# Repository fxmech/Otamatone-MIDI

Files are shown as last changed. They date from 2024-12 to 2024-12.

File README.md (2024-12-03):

Time lapse video of the full build available on my Youtube Page @fxmech314
https://youtu.be/D1--f7NfiHk?si=KnY27Ke7BcFxFsHI

The neck slider pot is not a potentiometer, but rather a rheostat, so while my wiring solution works, the output rage is limited from the usual 1024 steps down to 500...  I will need to revisit this.

The software has 3 modes.  
1: similar to original where the neck is just a long pitch bend wheel
2: Neck is mapped into a specific Major scale
3: Neck is mapped into a specific minor scale
The mode is mapped to the original 3 position switch on the Otamatone.

The Original volume know is also used to send midi signals to control volume or anything else you choose to map it too.

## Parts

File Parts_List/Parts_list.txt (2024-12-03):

1Pc Otamatone Techno.   I would guess that this would work on any full Sized Otamatone, but I cant be sure.  I did my build based on the Techno model.

1pc Ableton Live Software or similar to generate the audio...  It can also be a midi sound device such as a keyboard or sound module that accepts midi signals.  T

2pcs Uxcell 5pcs Fader Variable Resistors Mixer 18mm Straight Slide Potentiometer B102 B1K Ohm Linear Single Potentiometers for Dimming Tuning
Amazon $9.49 for pack of 5
https://www.amazon.com/dp/B07VY7TL75?ref=ppx_yo2ov_dt_b_fed_asin_title&th=1

1pc SeeedStudio XIOA SAMD21 microcontroller  $5.40 each
Mouser.com
https://www.mouser.com/ProductDetail/Seeed-Studio/102010328?qs=GBLSl2AkirtQWO8CTzEK9g%3D%3D

Resistors:
3pcs 10K Ohm for Selection Switch
1pc 120K Ohm resistor for neck Rheostat. Can be a 100K Ohm in series with a 22k Ohm as in the wiring diagram
 
NOTE:  This value might vary depending on the consistency in the original Otamatone parts.  I suggest starting with 120K and then adjusting up and down while looking at values on the Arduino debugger.  The idea resistance is the one that gives you the largest range in values.  I was getting about 500 range.  doesn't need to start at zero... just subtract the lowers value from the highest value and that is your range...  Go for the resistor that makes that number as high as possible.  In the future I will revisit this in order to raise the range to at least the full 0-1024.

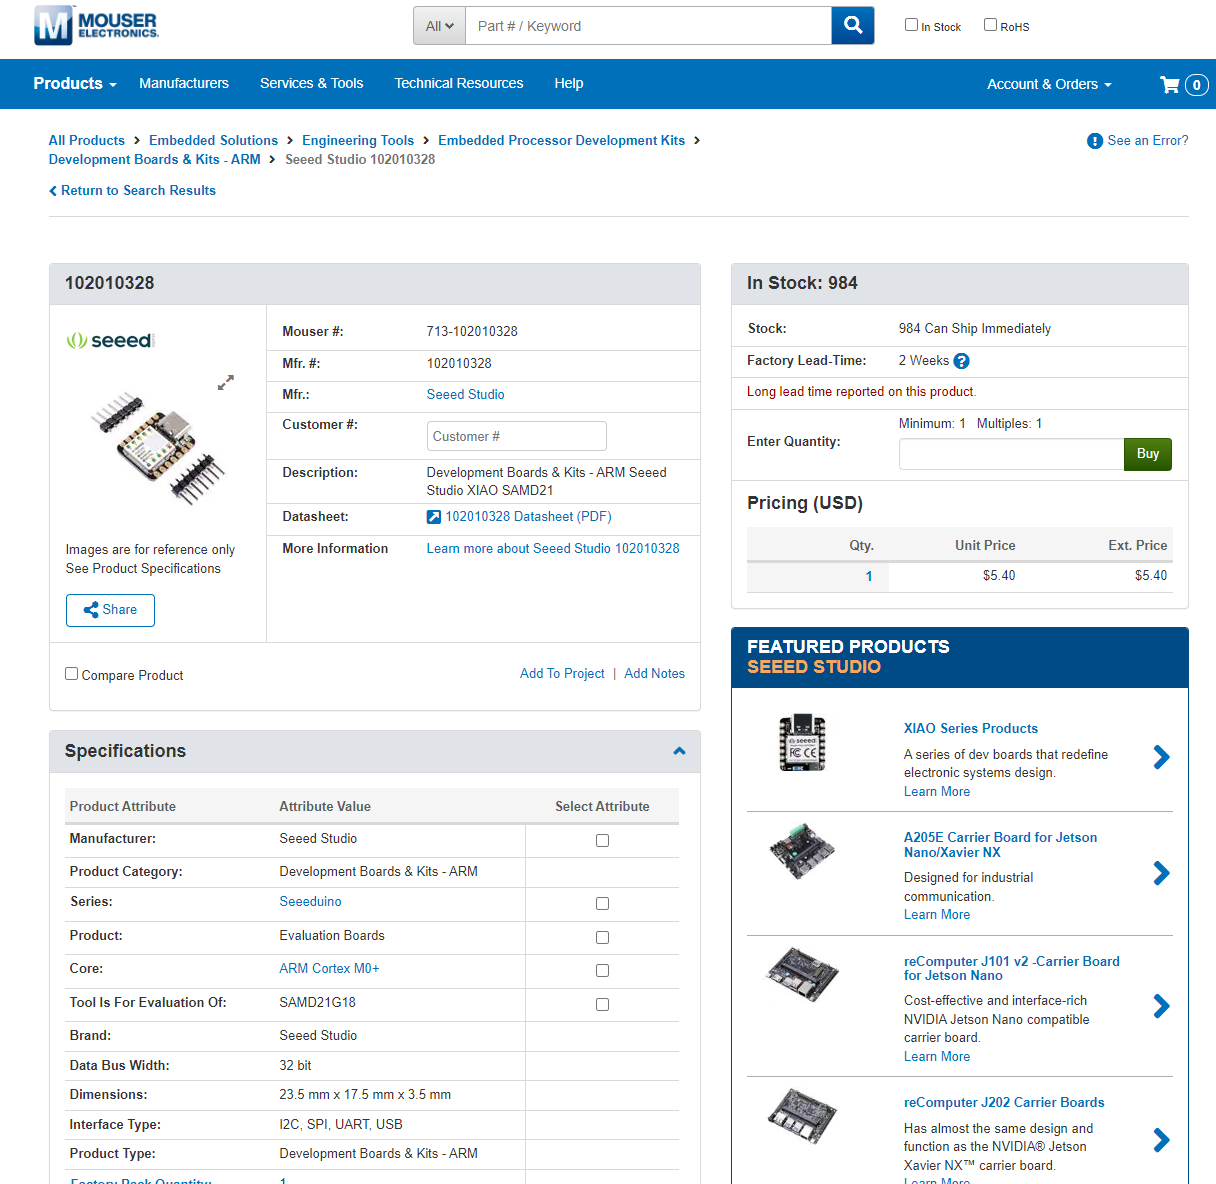
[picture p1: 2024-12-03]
Parts_List/Screenshot 2024-12-02 131504.png

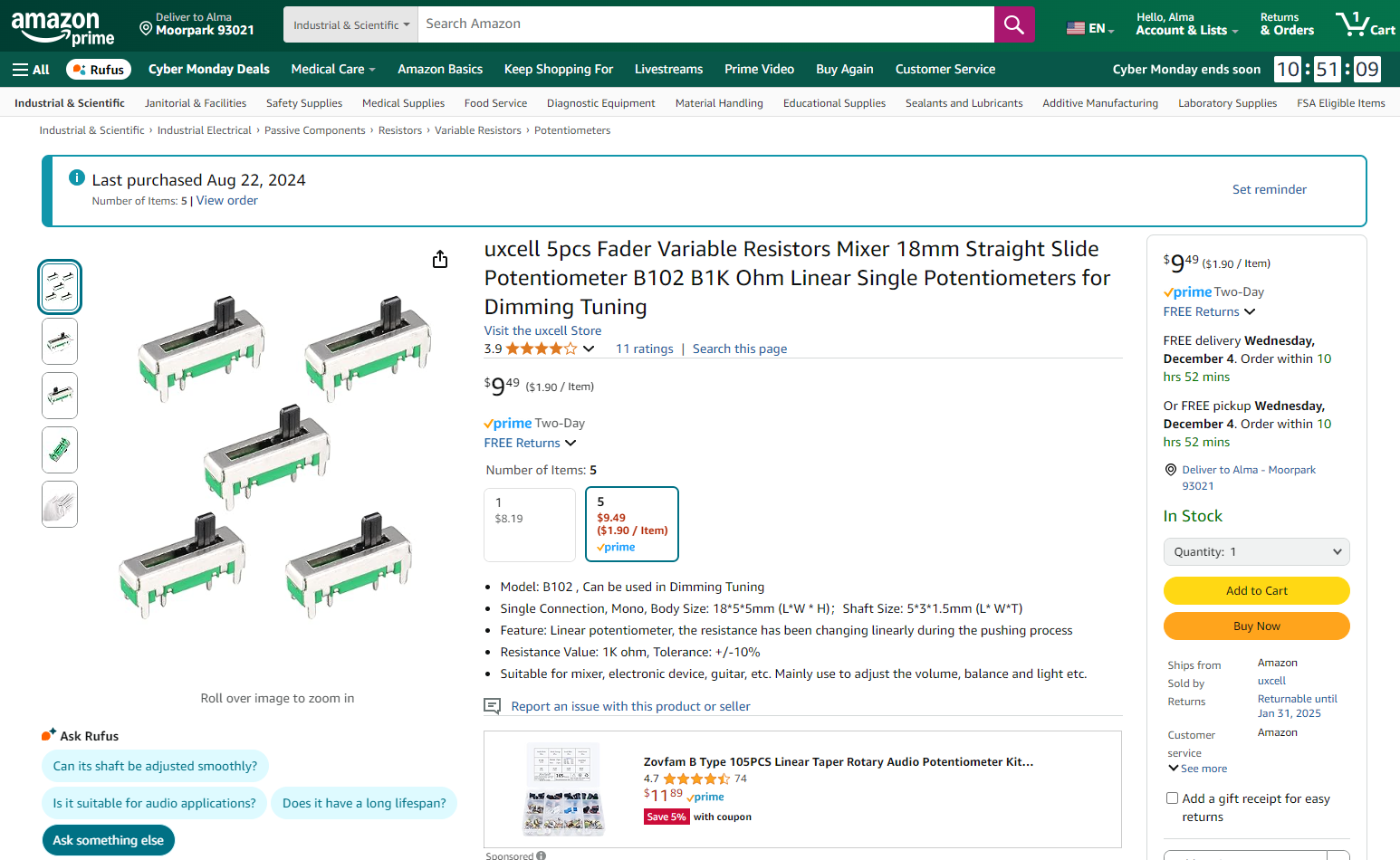
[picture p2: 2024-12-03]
Parts_List/Screenshot 2024-12-02 130912.png

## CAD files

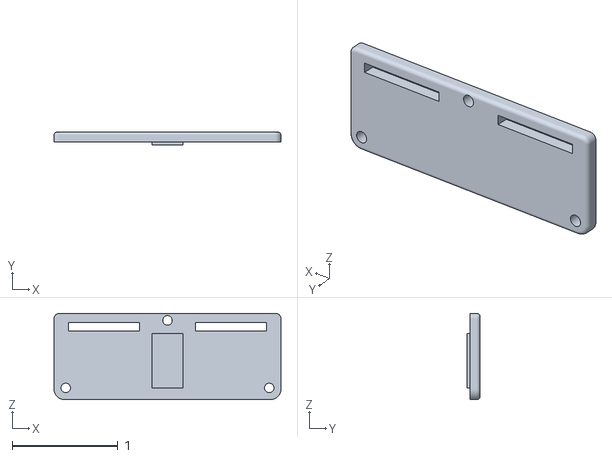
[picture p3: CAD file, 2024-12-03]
STL_Format/PlungerAssyCover_V2.stl
2.14 x 0.124 x 0.815

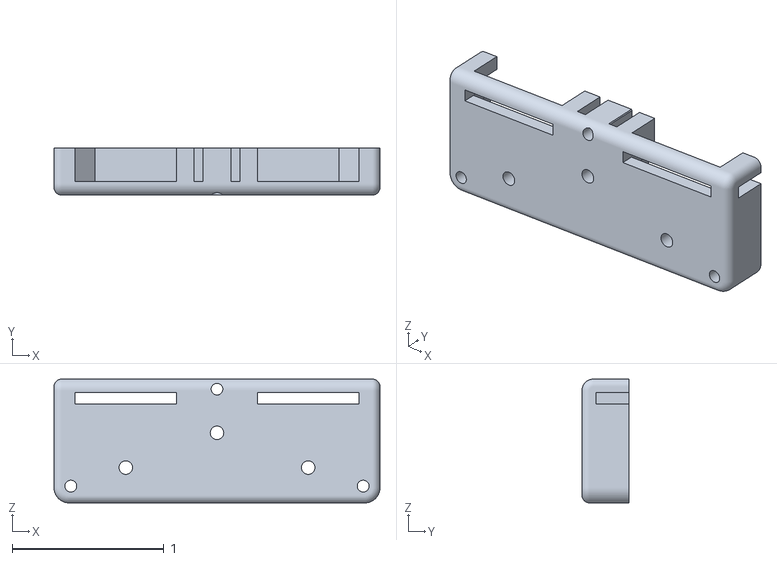
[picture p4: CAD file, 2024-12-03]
STL_Format/PlungerAssyHousing_V2.stl
2.14 x 0.31 x 0.815

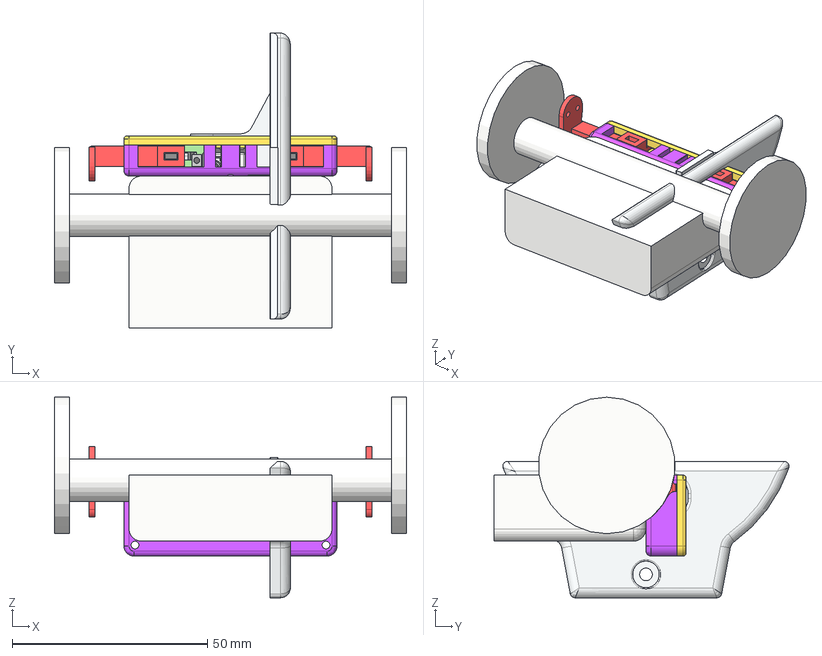
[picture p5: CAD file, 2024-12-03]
CAD_Format/Otamatone_MIDI v8.step
90.0 x 75.5 x 51.3 mm
type-c v2
smd_button v3
DOUT
DIN
VSS
VDD
smd_button v3(Mirror)
linearPot x 2
Cover
Otamatone

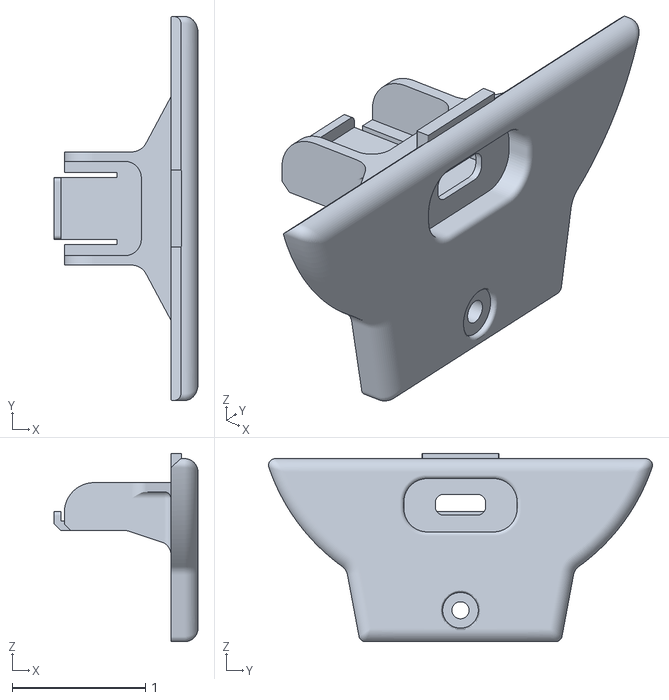
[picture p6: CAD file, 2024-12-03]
STL_Format/XIAO_HolderCover_V3.stl
1.08 x 2.88 x 1.42

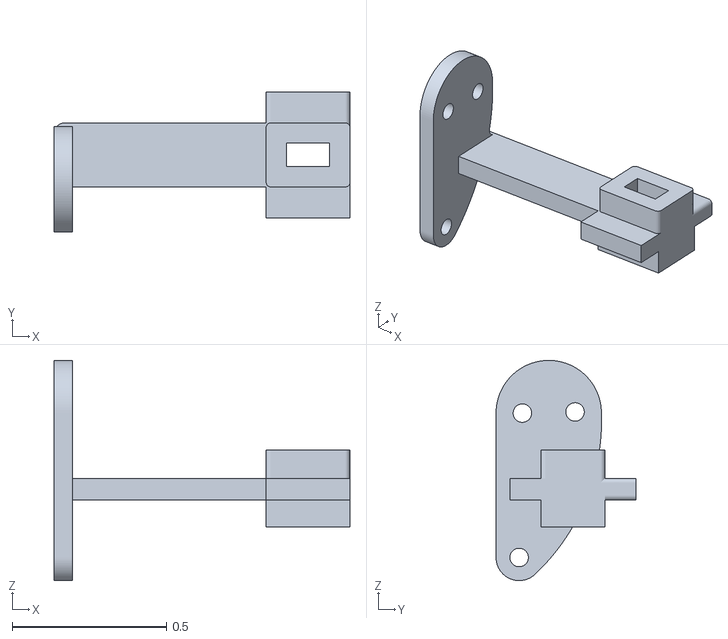
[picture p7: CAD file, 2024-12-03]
STL_Format/PlungerA_V2.stl
0.961 x 0.454 x 0.714

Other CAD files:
STL_Format/PlungerB_V2.stl
CAD_Format/Otamatone_MIDI v8.f3z

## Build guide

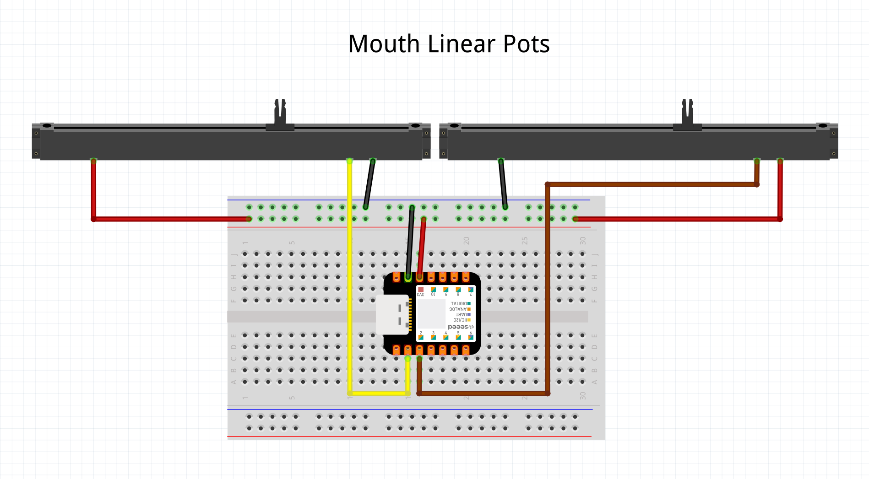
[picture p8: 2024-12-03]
Wiring_Diagram/MouthWiring.png

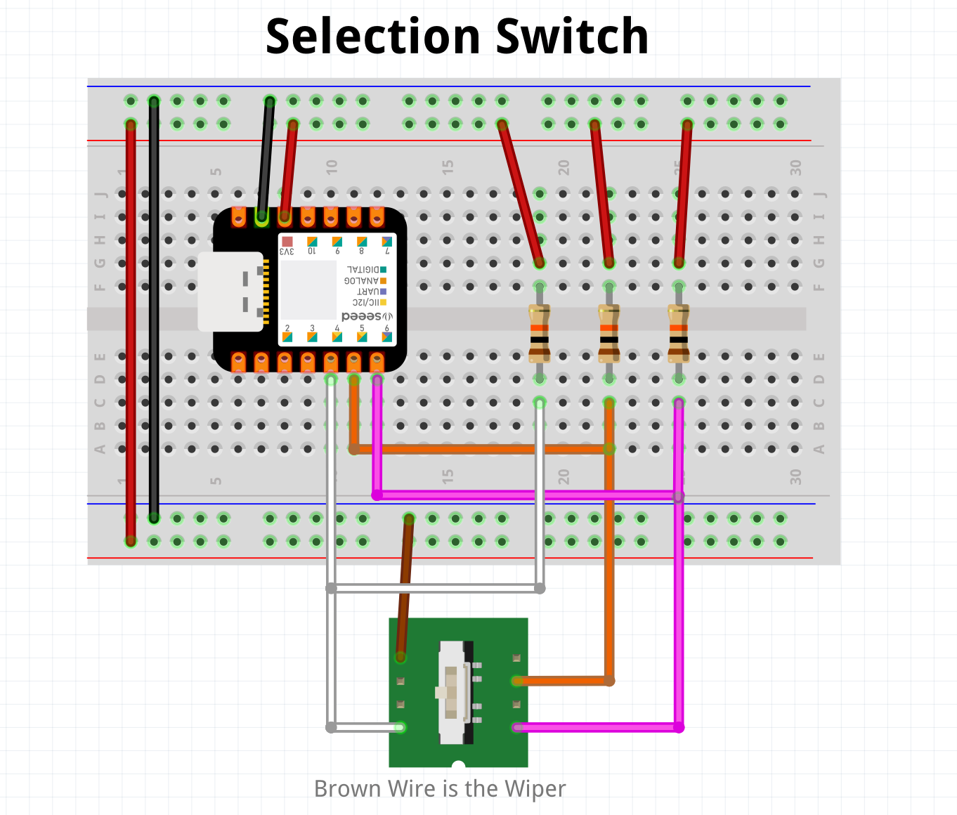
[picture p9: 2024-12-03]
Wiring_Diagram/SelectionSwitchWiring.png

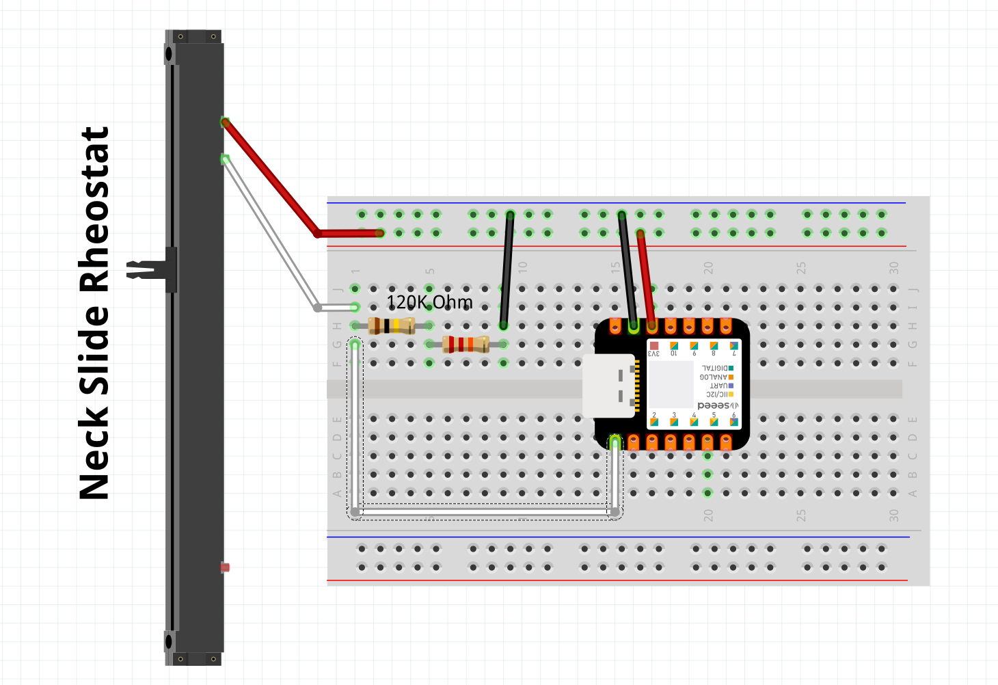
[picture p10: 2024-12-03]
Wiring_Diagram/NeckWiring.png

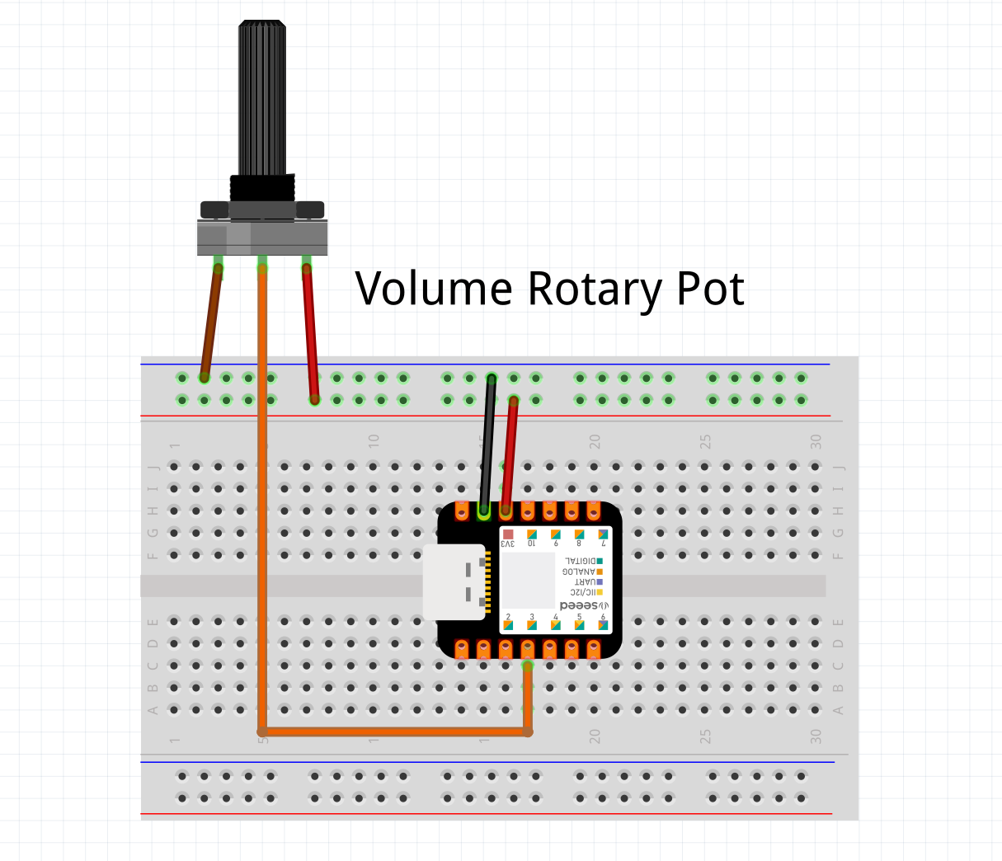
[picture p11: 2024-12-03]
Wiring_Diagram/VolumePotWiring.png

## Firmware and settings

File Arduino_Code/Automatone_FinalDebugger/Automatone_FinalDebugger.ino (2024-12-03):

#include <Arduino.h>
//#include <Adafruit_TinyUSB.h>
//#include <MIDI.h>

const int pitchPot = A0;
const int mouthPotR = A1;
const int mouthPotL = A2;
const int volumePot = A3;
const int switchLowPos = 5;
const int switchMidPos = 4;
const int switchHighPos = 6;

int lowNoteLimit[10] =  {421, 451, 481, 541, 601, 661, 721, 781, 841, 901};
int midNoteVal[10] =    {435, 465, 510, 570, 630, 690, 750, 810, 870, 920};
int highNoteLimit[10] = {450, 480, 540, 600, 661, 720, 780, 840, 900, 950};
//int scale1[10] = { -9, -8, -5, -4, -2, 0, 1, 3, 4, 7};
int scale1[10] = { 0, 1, 4, 5, 7, 9, 10, 12, 13, 16};
//int scale2[10] = { -8, -7, -5, -3, -2, 0, 2, 4, 5, 7};
int scale2[10] = { 0, 1, 3, 5, 6, 8, 10, 12, 13, 15};
int bend = 0;
int noteVal = 0;
int16_t pitch = 0;

long pitchPotVal = 0;
int16_t mouthVal = 0; //will be sum of the two mouth pots
int mouthValMapped = 0;
int volumePotVal = 0;
int volumePotValMapped = -5;
int prevVolumePotValMapped = -5;
bool switchLowPosVal = 0;
bool switchMidPosVal = 0;
bool switchHighPosVal = 0;

bool prevSwitchLowPosVal = 0;
bool prevSwitchMidPosVal = 0;
bool prevSwitchHighPosVal = 0;
int prevPitch = -1;
int prevPitchPotVal = 0;
int prevMouthVal = 0;
int prevVolumePotVal = 0;
int pitchPotValDiff = 0;

const int diffPitchPots = 40;
const int diffMouthPots = 0;
const int diffVolumePot = 40;

unsigned long lastDebounceTime = 0;  // the last time the output pin was toggled
unsigned long debounceDelay = 150; // time to ignore a change in notes

int noteScale = 1;

//Adafruit_USBD_MIDI usb_midi;
//MIDI_CREATE_INSTANCE(Adafruit_USBD_MIDI, usb_midi, MIDI);

void setup() {
  //MIDI.begin(MIDI_CHANNEL_OMNI);
Serial.begin(115200);
  pinMode(switchLowPos, INPUT);
  pinMode(switchMidPos, INPUT);
  pinMode(switchHighPos, INPUT);
}


void loop() {
  //MIDI.read();
  readSensors();

  //select play mode
  if (!switchLowPosVal && !prevSwitchLowPosVal) { //if witch is on low and was on low before
    freeformMode(); //play in freeform
  } 
  if (!switchMidPosVal && !prevSwitchMidPosVal) { //if witch is on mid and was on mid before
    noteScale = 1; //play in scale mode A
    playScale();
  }
  if (!switchHighPosVal && !prevSwitchHighPosVal) { //if witch is on high and was on high before
    noteScale = 2; //play in scale mode B
    playScale();
  } 
}

void resetModes() {
  bend = 0;
  noteVal = 0;
  pitch = 0;
  pitchPotVal = 0;
  mouthVal = 0; //will be sum of the two mouth pots
  mouthValMapped = 0;
  volumePotVal = 0;
  volumePotValMapped = 125;
  prevVolumePotValMapped = 125;

  //prevPitch = -1;
  prevPitchPotVal = 0;
  prevMouthVal = 0;
  prevVolumePotVal = 0;
  pitchPotValDiff = 0;
}

void freeformMode() { //factory style slider method

  //read Pitch Pot
  for (int u = 0; u < 20; u++) { //average data to filter
    pitchPotVal = pitchPotVal + analogRead(pitchPot);
    //delay(5);
  }
  pitchPotVal = pitchPotVal / 20;
  pitchPotValDiff = pitchPotVal - prevPitchPotVal;
  pitch = map(pitchPotVal, 400, 900, -1000, 1000); //pitchbend
  pitch = constrain(pitch, -1000, 1000) * 8;

  volumePotValMapped = map(volumePotVal, 0, 1023, -15, 15); //map volume pot to adjust the key mid point
  volumePotValMapped = constrain(volumePotValMapped, -15, 15);

  if (pitchPotVal > 400) { //slider is being pushed down on
    if (prevPitchPotVal < 400) { //if it wasnt pressed before
      //MIDI.sendNoteOn(60 + volumePotValMapped, 127, 1); //note ON
      delay(20);
      prevVolumePotValMapped = volumePotValMapped;
    }

    //if (abs(pitchPotValDiff) > diffPitchPots) { //if difference is big enough do pitchbend
    //MIDI.sendPitchBend(pitch, 1);
    delay(20);
    //}
  } else {
    //MIDI.sendNoteOff(60 + prevVolumePotValMapped, 0, 1); //of no slider push then note OFF
    delay(20);

  }

  mouthValMapped = map(mouthVal, 85, 1023, 55, 127);
  //MIDI.sendControlChange(16, mouthValMapped, 1);
  delay(20);
  prevPitchPotVal = pitchPotVal;
}


void playScale() {
  // READ AND AVERAGE 20 PITCH POT VALUES
  for (int u = 1; u <= 20; u++) { //average data to filter
    pitchPotVal = pitchPotVal + analogRead(pitchPot);
  }
  pitchPotVal = pitchPotVal / 20;
//Serial.print(pitchPotVal);Serial.print("   ");
  for (int i = 0; i < 10; i++) {
    if (pitchPotVal >= lowNoteLimit[i] && pitchPotVal <= highNoteLimit[i]) {
      pitch = i;
    }
  }

  mouthValMapped = map(mouthVal, 85, 1023, 55, 127);
  Serial.print("M:");Serial.println(mouthValMapped);
  //MIDI.sendControlChange(16, mouthValMapped, 1);
  delay(20);
  //volumePotValMapped = map(volumePotVal, 0, 1023, -8, 8); //map volume pot to adjust the key mid point
  //volumePotValMapped = constrain(volumePotValMapped, -8, 8);

  if (pitchPotVal >= 100) { //Do this if pitch pot is being pressed on
    if (prevPitch != pitch) { //Do this if note changed
      if ((millis() - lastDebounceTime) > debounceDelay) {
        if (noteScale == 1) {
          //MIDI.sendNoteOn(60 + volumePotValMapped + scale1[pitch], 127, 1); //(pitch, 1);
          delay(20);
          //MIDI.sendNoteOff(60 + volumePotValMapped + scale1[prevPitch], 0, 1);
          delay(20);
          Serial.print("1:"); Serial.println(pitch);
        } else if (noteScale == 2) {
          //MIDI.sendNoteOn(60 + volumePotValMapped + scale2[pitch], 127, 1); //(pitch, 1);
          delay(20);
          //MIDI.sendNoteOff(60 + volumePotValMapped + scale2[prevPitch], 0, 1);
          delay(20);
          Serial.print("2:"); Serial.println(pitch);
        }
        prevPitch = pitch;
        lastDebounceTime = millis();
      }
    } else {
      //Do nothing
    }
  } else {
    lastDebounceTime = millis();
    //MIDI.sendControlChange(123, 0, 1);
    //Serial.println("STOP");
    delay(20);
    prevPitch = -1;
    bend = 0;
  }
}

void readSensors() {

  // READ PITCH BEND POT Is handled differently in each mode
  //so it is not read here but instead is read inside the specificmode setion

  //Read Mouth Pots
  mouthVal = (analogRead(mouthPotR) + analogRead(mouthPotL)) / 2; //sum of both mouth pots
Serial.print(mouthVal);Serial.print("  ");
  //Read Volume Pot
  //volumePotVal = analogRead(volumePot);
  //delay(5);
  //Read Low/Mid/High Switch
  prevSwitchLowPosVal = switchLowPosVal;
  prevSwitchMidPosVal = switchMidPosVal;
  prevSwitchHighPosVal = switchHighPosVal;
  switchLowPosVal = digitalRead(switchLowPos);
  switchMidPosVal = digitalRead(switchMidPos);
  switchHighPosVal = digitalRead(switchHighPos);
}
